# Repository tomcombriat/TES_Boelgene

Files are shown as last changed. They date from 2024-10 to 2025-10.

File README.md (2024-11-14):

# TES - Bølgene

Bølgene is a digital instrument inspired by the [Ondes Martenot](https://en.wikipedia.org/wiki/Ondes_Martenot), a contemporary instrument to the Theremin.
The original instrument features a force sensitive button for the expression/volume and continuous pitch controlled by the position of a ring.

Bølgene is a small, table-top, digital, instrument having the base features. The main differences is that it features polyphony, with several pressure sensitive buttons.

Bølgene (first version) was created in a few weeks specially for [Oslo Skaper Festival 2024](https://norwaymakers.org/osf24). 

## v1

### Hardware

Nothing special here except a well sized plank, found in the street. Apart from that…
 - CPU: RP2040
 - additionnal ADC: MCP3008
 - DAC: PT8211
 - expressions buttons: 4
 - synthesis potentiometers:

Made on single sided PCB.

### Software
 - sound system: [Mozzi](https://sensorium.github.io/Mozzi/)

#### boelgene_1

The version presented at Oslo Skaper Festival, monophonic with Delay Feedback creating weird sounds, especially in the bass register.

#### boelgene_poly 

Version supporting 4 expression buttons, currently tuned to the fifth and the two thirds. Uses the same synthesis algorithm than boelgene_v1

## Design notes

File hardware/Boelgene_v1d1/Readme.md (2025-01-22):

# Building instructions and details

This document contains details and building information for Bølgene v1.1.

## General information

This version of Bølgene is a small step from the v1 which was based on a one-sided PCB.
As the previous version, this is based on a Raspberry Pico (RP2040) MCU and a PT8211 DAC. Because of the low number of analog inputs on the RP2040, a companion ADC is also used.

## Audio modes

The PCB supports three audio modes:

 - PWM straight from the RP2040. Resolution is 12bits. All DAC components can then be omitted (PT8211, C9, C10, C11 and C12) and normally C2, C3 and R1.
 - mono output: components for the PWM can be omitted (C7 and C8) and components for the right channel (C10, C12). This outputs a 16bits signal on `out_dac1`.
 - stereo output: components for the PWM can be omitted (C7 and C8). This outputs a 16bits signal on `out_dac1` and `out_dac2`.
 
All outputs do not have volume control as of the PCB. An external log potentiometer can be adjucted.

## Analog inputs

There are a few analog signals that are measured:

### Pressure (touch):

These are measured wih the help of resisor dividers (RV1-4) and are to be connected to force sensitive resistors (range 1.5kg, ref in BOM). The pots are adjusting the sensitivity of the pressure sensors.

## Ribbon

This is to be connected to the central pin of a 10 turns, 10k linear potentiometer. The other two pins should be connected to GNDA and ADC_ref. 

## Synthesis input

There are currently 5 potentiometers to adjust the synthesis parameters. There is a free slot so a sixth could be added.

The test points labelled pot1-5 are to be connected to the central pin (10k linear), and the other two to GNDA and ADC_ref.

## Power

As of now, the system is powered by four AA batteries giving a nominal voltage of 4*1.2 = 4.8V. The only limitation there are the IC voltage tolerances: RP2040 is given fine up to 6V, PT8211 up to 7V.

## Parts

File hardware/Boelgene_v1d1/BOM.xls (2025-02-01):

Id | Référence | Boîtier | Quantité | Désignation | Fournisseur et réf | Extra info
1 | R3 | R_Axial_DIN0207_L6.3mm_D2.5mm_P7.62mm_Horizontal | 1 | 220
2 | TP18 | TestPoint_THTPad_2.0x2.0mm_Drill1.0mm | 1 | Ref- |  | Sound board, low point reference switch (switch is to shut to GND)
3 | H1,H3,H4,H2 | MountingHole_3.2mm_M3 | 4 | MountingHole
4 | TP7,TP8,TP12,TP6,TP5,TP1 | TestPoint_THTPad_2.0x2.0mm_Drill1.0mm | 6 | GND
5 | TP22,TP24,TP23,TP25,TP21,TP26 | TestPoint_THTPad_2.0x2.0mm_Drill1.0mm | 6 | GNDA |  | Analog Ground
6 | TP33 | TestPoint_THTPad_2.0x2.0mm_Drill1.0mm | 1 | pot4
7 | TP17 | TestPoint_THTPad_2.0x2.0mm_Drill1.0mm | 1 | LED
8 | TP16 | TestPoint_THTPad_2.0x2.0mm_Drill1.0mm | 1 | D5 |  | Unused
9 | C6 | CP_Radial_D5.0mm_P2.00mm | 1 | 1u
10 | J3 | JST_XH_B2B-XH-A_1x02_P2.50mm_Vertical | 1 | pressure2 |  | To be connected to a force sensitive resistor like : https://fr.aliexpress.com/item/1005006212871655.html
11 | J4 | JST_XH_B2B-XH-A_1x02_P2.50mm_Vertical | 1 | pressure1 |  | To be connected to a force sensitive resistor like : https://fr.aliexpress.com/item/1005006212871655.html
12 | J1 | JST_XH_B2B-XH-A_1x02_P2.50mm_Vertical | 1 | batt |  | Battery input (4.5-6V)
13 | TP9,TP10,TP3,TP11,TP2,TP4 | TestPoint_THTPad_2.0x2.0mm_Drill1.0mm | 6 | ADC_ref
14 | TP43 | TestPoint_THTPad_2.0x2.0mm_Drill1.0mm | 1 | out_PWM |  | Audio output for PWM mode
15 | J5 | JST_XH_B2B-XH-A_1x02_P2.50mm_Vertical | 1 | pressure4 |  | To be connected to a force sensitive resistor like : https://fr.aliexpress.com/item/1005006212871655.html
16 | U1 | RPi_Pico_SMD_TH | 1 | Pico |  | Raspberry pico 2040
17 | RV2 | Potentiometer_Runtron_RM-065_Vertical | 1 | 20k_adj2
18 | RV3 | Potentiometer_Runtron_RM-065_Vertical | 1 | 20k_adj1
19 | TP13 | TestPoint_THTPad_2.0x2.0mm_Drill1.0mm | 1 | D2 |  | Unused
20 | C9,C11 | CP_Radial_D5.0mm_P2.50mm | 2 | 1u dac1
21 | TP32 | TestPoint_THTPad_2.0x2.0mm_Drill1.0mm | 1 | pot5
22 | RV4 | Potentiometer_Runtron_RM-065_Vertical | 1 | 20k_adj4
23 | C2,C4 | CP_Radial_D8.0mm_P5.00mm | 2 | 100u
24 | C5,C3 | C_Axial_L3.8mm_D2.6mm_P7.50mm_Horizontal | 2 | 100n
25 | RV1 | Potentiometer_Runtron_RM-065_Vertical | 1 | 20k_adj3
26 | R1,R2 | R_Axial_DIN0207_L6.3mm_D2.5mm_P7.62mm_Horizontal | 2 | 10
27 | TP14 | TestPoint_THTPad_2.0x2.0mm_Drill1.0mm | 1 | Ref+ |  | Sound board, high point reference switch
28 | C10,C12 | CP_Radial_D5.0mm_P2.50mm | 2 | 1u dac2 |  | Unused in Mono
29 | TP19 | TestPoint_THTPad_2.0x2.0mm_Drill1.0mm | 1 | Oct+ |  | Oct + switch (switch should shut to GND)
30 | TP42 | TestPoint_THTPad_2.0x2.0mm_Drill1.0mm | 1 | 3.3V
31 | TP35 | TestPoint_THTPad_2.0x2.0mm_Drill1.0mm | 1 | pot2
32 | TP20 | TestPoint_THTPad_2.0x2.0mm_Drill1.0mm | 1 | Oct-
33 | TP28 | TestPoint_THTPad_2.0x2.0mm_Drill1.0mm | 1 | AI27 |  | Ribbon (linear 10 turn pot 10k) input : https://fr.aliexpress.com/item/1005003756851148.html
34 | TP27 | TestPoint_THTPad_2.0x2.0mm_Drill1.0mm | 1 | AI28 |  | Unused (free analog channel)
35 | J2 | JST_XH_B2B-XH-A_1x02_P2.50mm_Vertical | 1 | pressure3 |  | To be connected to a force sensitive resistor like : https://fr.aliexpress.com/item/1005006212871655.html
36 | TP44 | TestPoint_THTPad_2.0x2.0mm_Drill1.0mm | 1 | out_dac1 |  | Audio output for Mono and Left for stereo
37 | TP36 | TestPoint_THTPad_2.0x2.0mm_Drill1.0mm | 1 | pot1
38 | C1 | C_Axial_L3.8mm_D2.6mm_P7.50mm_Horizontal | 1 | 0.1u
39 | TP15 | TestPoint_THTPad_2.0x2.0mm_Drill1.0mm | 1 | D4 |  | Unused
40 | TP34 | TestPoint_THTPad_2.0x2.0mm_Drill1.0mm | 1 | pot3
41 | U2 | DIP-16_W7.62mm | 1 | MCP3008 |  | external ADC
42 | C7,C8 | CP_Radial_D5.0mm_P2.50mm | 2 | 1u pwm
43 | TP45 | TestPoint_THTPad_2.0x2.0mm_Drill1.0mm | 1 | out_dac2 |  | Unused in Mono
44 | U3 | SOP-8_3.9x4.9mm_P1.27mm | 1 | PT8211-pt8211 |  | DAC

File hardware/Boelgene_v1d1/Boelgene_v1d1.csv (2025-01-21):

Id | Référence | Boîtier | Quantité | Désignation | Fournisseur et réf
1 | R3 | R_Axial_DIN0207_L6.3mm_D2.5mm_P7.62mm_Horizontal | 1 | 220
2 | TP18 | TestPoint_THTPad_2.0x2.0mm_Drill1.0mm | 1 | Ref-
3 | H1,H3,H4,H2 | MountingHole_3.2mm_M3 | 4 | MountingHole
4 | TP7,TP8,TP12,TP6,TP5,TP1 | TestPoint_THTPad_2.0x2.0mm_Drill1.0mm | 6 | GND
5 | TP22,TP24,TP23,TP25,TP21,TP26 | TestPoint_THTPad_2.0x2.0mm_Drill1.0mm | 6 | GNDA
6 | TP33 | TestPoint_THTPad_2.0x2.0mm_Drill1.0mm | 1 | pot4
7 | TP17 | TestPoint_THTPad_2.0x2.0mm_Drill1.0mm | 1 | LED
8 | TP16 | TestPoint_THTPad_2.0x2.0mm_Drill1.0mm | 1 | D5
9 | C6 | CP_Radial_D5.0mm_P2.00mm | 1 | 1u
10 | J3 | JST_XH_B2B-XH-A_1x02_P2.50mm_Vertical | 1 | pressure2
11 | J4 | JST_XH_B2B-XH-A_1x02_P2.50mm_Vertical | 1 | pressure1
12 | J1 | JST_XH_B2B-XH-A_1x02_P2.50mm_Vertical | 1 | batt
13 | TP9,TP10,TP3,TP11,TP2,TP4 | TestPoint_THTPad_2.0x2.0mm_Drill1.0mm | 6 | ADC_ref
14 | TP43 | TestPoint_THTPad_2.0x2.0mm_Drill1.0mm | 1 | out_PWM
15 | J5 | JST_XH_B2B-XH-A_1x02_P2.50mm_Vertical | 1 | pressure4
16 | U1 | RPi_Pico_SMD_TH | 1 | Pico
17 | RV2 | Potentiometer_Runtron_RM-065_Vertical | 1 | 20k_adj2
18 | RV3 | Potentiometer_Runtron_RM-065_Vertical | 1 | 20k_adj1
19 | TP13 | TestPoint_THTPad_2.0x2.0mm_Drill1.0mm | 1 | D2
20 | C9,C11 | CP_Radial_D5.0mm_P2.50mm | 2 | 1u dac1
21 | TP32 | TestPoint_THTPad_2.0x2.0mm_Drill1.0mm | 1 | pot5
22 | RV4 | Potentiometer_Runtron_RM-065_Vertical | 1 | 20k_adj4
23 | C2,C4 | CP_Radial_D8.0mm_P5.00mm | 2 | 100u
24 | C5,C3 | C_Axial_L3.8mm_D2.6mm_P7.50mm_Horizontal | 2 | 100n
25 | RV1 | Potentiometer_Runtron_RM-065_Vertical | 1 | 20k_adj3
26 | R1,R2 | R_Axial_DIN0207_L6.3mm_D2.5mm_P7.62mm_Horizontal | 2 | 10
27 | TP14 | TestPoint_THTPad_2.0x2.0mm_Drill1.0mm | 1 | Ref+
28 | C10,C12 | CP_Radial_D5.0mm_P2.50mm | 2 | 1u dac2
29 | TP19 | TestPoint_THTPad_2.0x2.0mm_Drill1.0mm | 1 | Oct+
30 | TP42 | TestPoint_THTPad_2.0x2.0mm_Drill1.0mm | 1 | 3.3V
31 | TP35 | TestPoint_THTPad_2.0x2.0mm_Drill1.0mm | 1 | pot2
32 | TP20 | TestPoint_THTPad_2.0x2.0mm_Drill1.0mm | 1 | Oct-
33 | TP28 | TestPoint_THTPad_2.0x2.0mm_Drill1.0mm | 1 | AI27
34 | TP27 | TestPoint_THTPad_2.0x2.0mm_Drill1.0mm | 1 | AI28
35 | J2 | JST_XH_B2B-XH-A_1x02_P2.50mm_Vertical | 1 | pressure3
36 | TP44 | TestPoint_THTPad_2.0x2.0mm_Drill1.0mm | 1 | out_dac1
37 | TP36 | TestPoint_THTPad_2.0x2.0mm_Drill1.0mm | 1 | pot1
38 | C1 | C_Axial_L3.8mm_D2.6mm_P7.50mm_Horizontal | 1 | 0.1u
39 | TP15 | TestPoint_THTPad_2.0x2.0mm_Drill1.0mm | 1 | D4
40 | TP34 | TestPoint_THTPad_2.0x2.0mm_Drill1.0mm | 1 | pot3
41 | U2 | DIP-16_W7.62mm | 1 | MCP3008
42 | C7,C8 | CP_Radial_D5.0mm_P2.50mm | 2 | 1u pwm
43 | TP45 | TestPoint_THTPad_2.0x2.0mm_Drill1.0mm | 1 | out_dac2
44 | U3 | SOP-8_3.9x4.9mm_P1.27mm | 1 | PT8211-pt8211

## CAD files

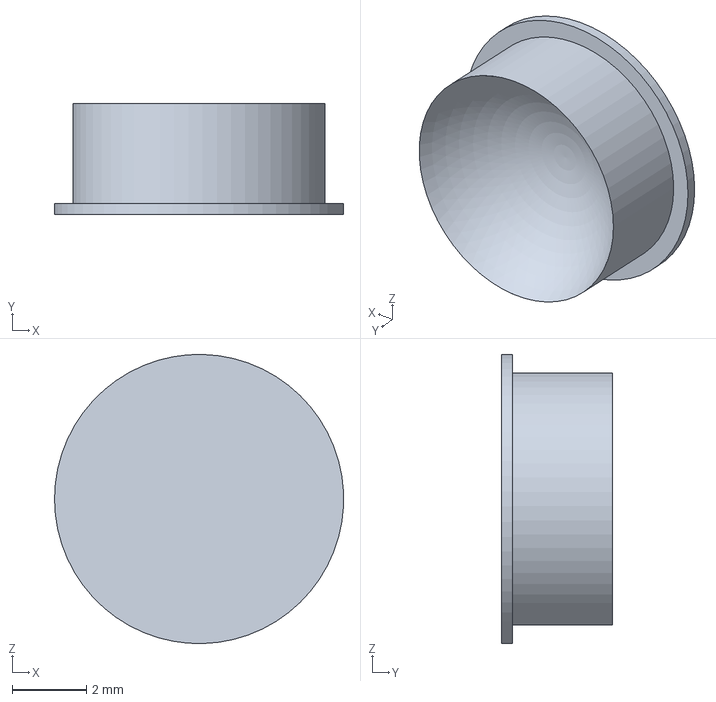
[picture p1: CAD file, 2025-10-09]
hardware/3D_proto2/FingerBoard/full_fret.FCStd
7.79 x 3.00 x 7.80 mm

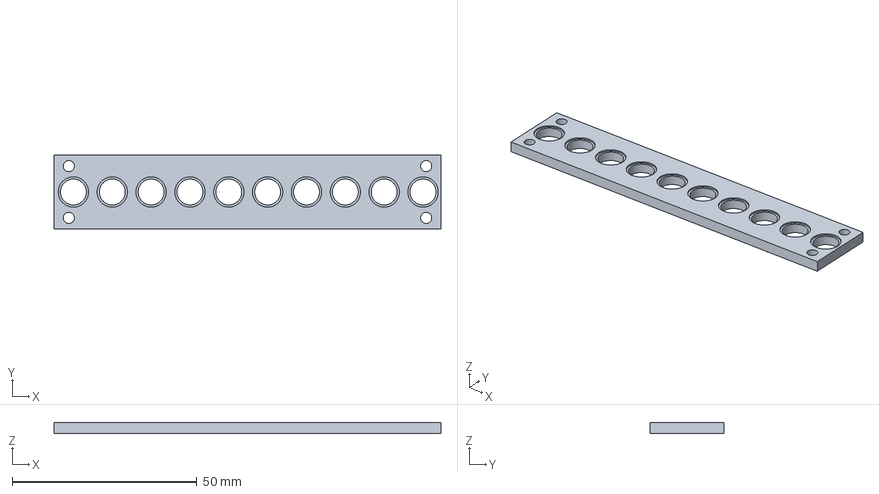
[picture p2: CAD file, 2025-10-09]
hardware/3D_proto2/FingerBoard/half_base_20holes.FCStd
104.6 x 20.0 x 3.00 mm

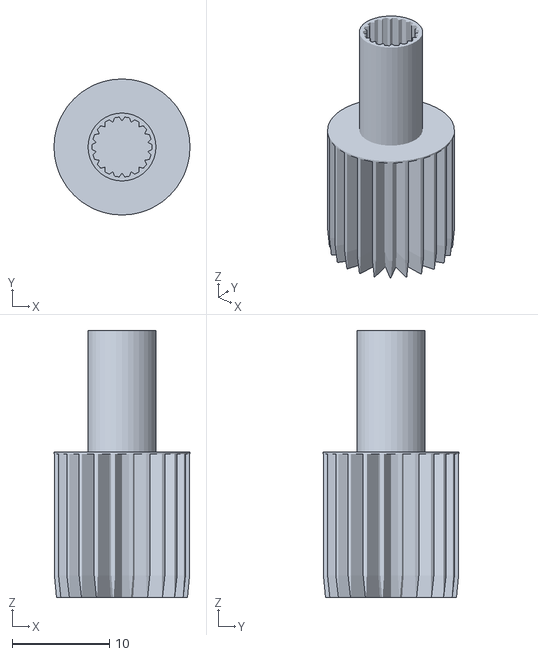
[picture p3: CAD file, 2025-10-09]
hardware/3D_proto2/pot_top4_part1.STL
14.0 x 14.0 x 27.5

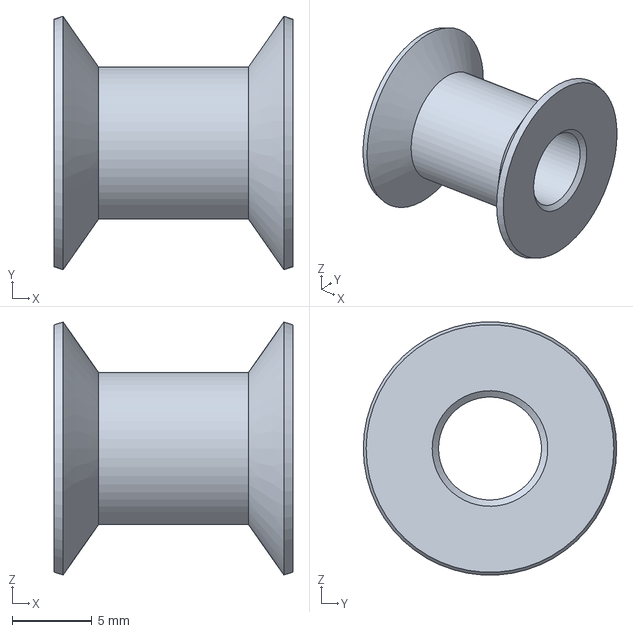
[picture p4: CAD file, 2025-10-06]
hardware/3D_proto2/Ribbon/potentiometer_pulley.FCStd
15.0 x 15.9 x 15.9 mm

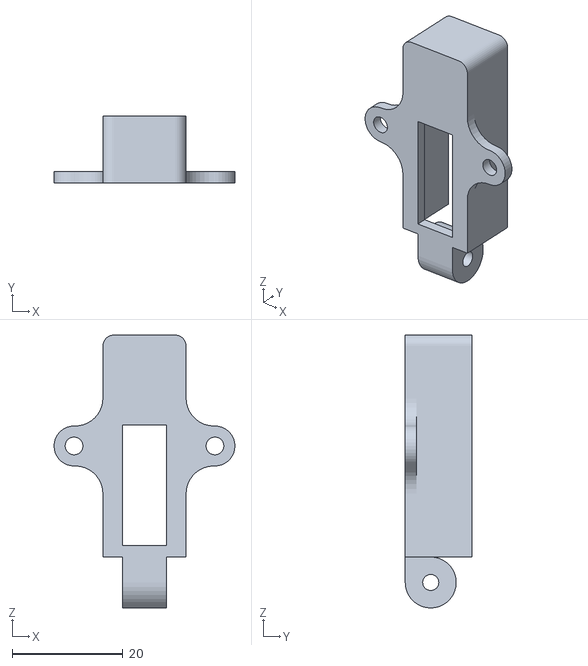
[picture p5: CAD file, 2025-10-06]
hardware/3D_proto2/Volume_Button/Bottom_common_1.STL
32.6 x 12.0 x 49.2

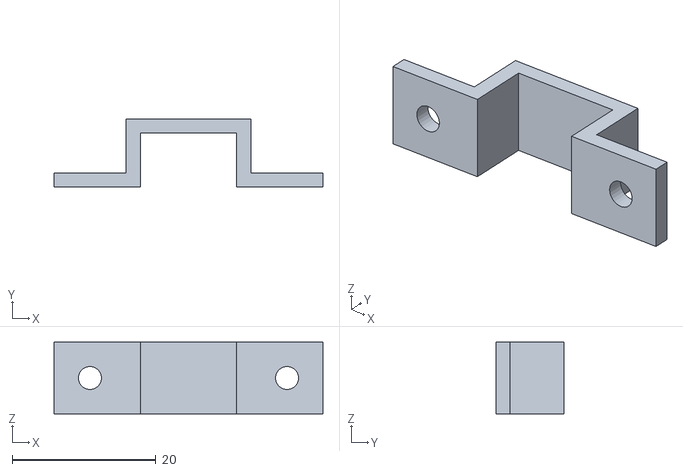
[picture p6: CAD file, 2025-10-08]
hardware/3D_proto2/OnOff_holder-Corps.stl
37.4 x 9.50 x 10.0

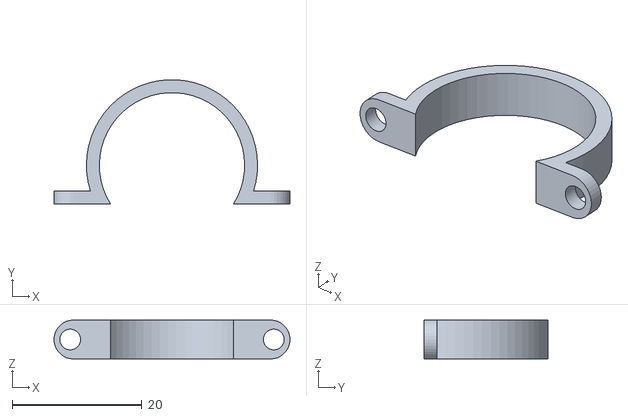
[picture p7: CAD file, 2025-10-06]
hardware/3D_proto2/Ribbon/top_potentiometer.STL
36.4 x 19.2 x 6.00

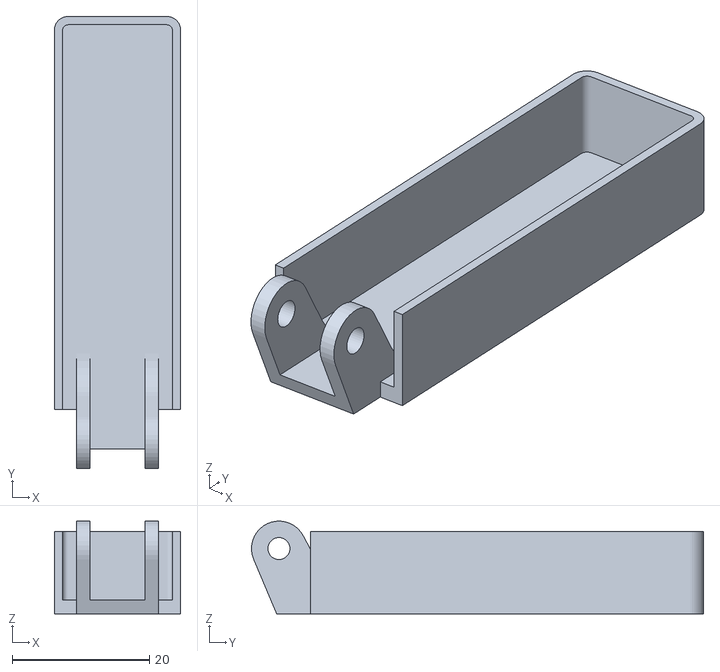
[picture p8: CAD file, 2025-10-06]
hardware/3D_proto2/Volume_Button/Top_oversize_1.STL
18.4 x 65.8 x 13.5

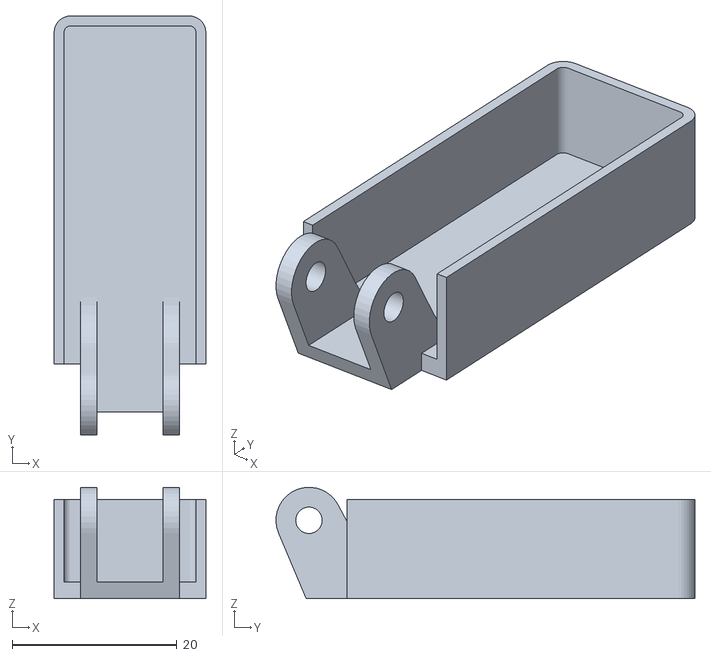
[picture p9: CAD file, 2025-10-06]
hardware/3D_proto2/Volume_Button/Top_common_1.STL
18.4 x 50.8 x 13.5

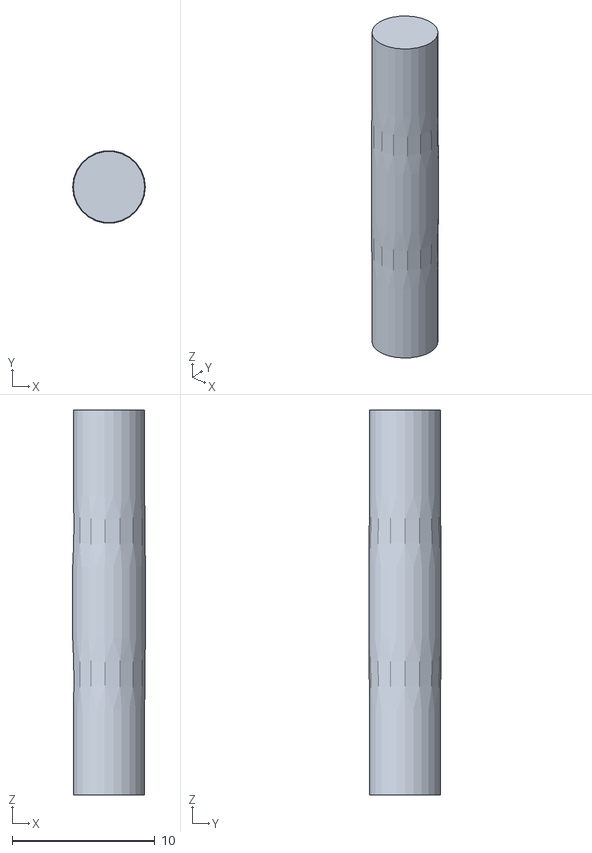
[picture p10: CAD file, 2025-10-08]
hardware/3D_proto2/axis_small_idler_bump-Corps.stl
5.10 x 5.06 x 27.0

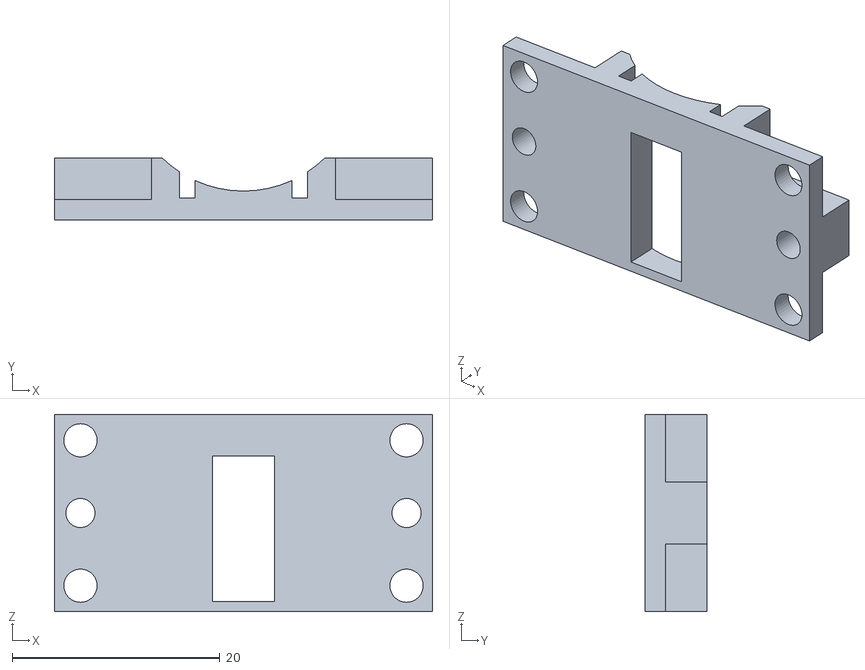
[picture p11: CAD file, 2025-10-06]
hardware/3D_proto2/Ribbon/bottom_potentiometer.STL
36.4 x 6.00 x 19.0

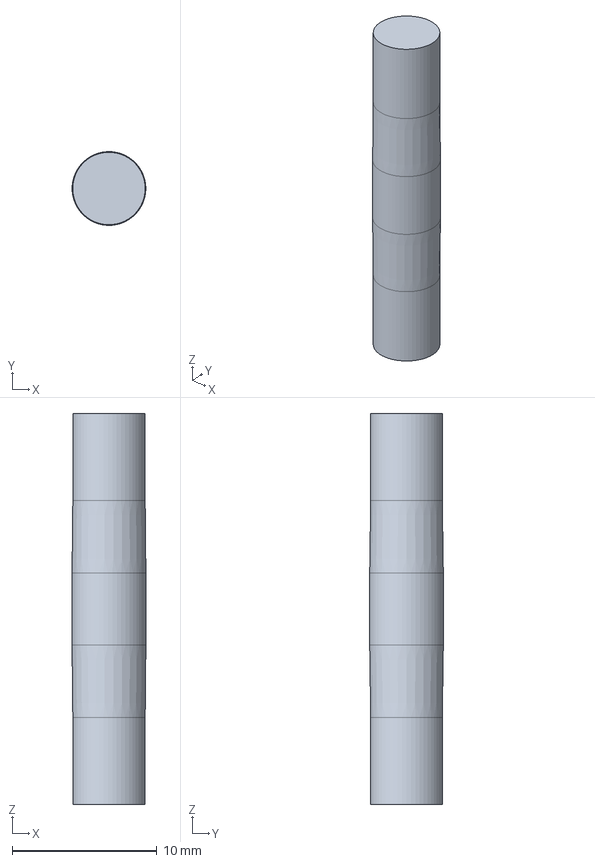
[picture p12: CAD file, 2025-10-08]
hardware/3D_proto2/axis_small_idler_bump.FCStd
5.10 x 5.10 x 27.0 mm

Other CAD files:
hardware/3D_proto2/FingerBoard/full_fret-Corps.stl
hardware/3D_proto2/FingerBoard/assembly.FCStd
hardware/3D_proto2/OnOff_holder.FCStd
hardware/3D_proto2/Ribbon/potentiometer_pulley-Corps.stl
hardware/3D_proto2/FingerBoard/half_base_13holes.FCStd
hardware/3D_proto2/FingerBoard/half_base-Corps.stl
hardware/3D_proto2/FingerBoard/half_base.FCStd
hardware/3D_proto2/FingerBoard/half_base_13holes-Corps.stl
hardware/3D_proto2/FingerBoard/half_base_20holes-Corps.stl
hardware/3D_proto2/axis_small_idler-Corps.stl
hardware/3D_proto2/axis_small_idler.FCStd
hardware/3D_proto2/battery_holder.STL
hardware/3D_proto2/cable_holder.STL
hardware/3D_proto2/cover_small_idler_holder-cover.stl
hardware/3D_proto2/cover_small_idler_holder.FCStd
hardware/3D_proto2/jack_support.STL
hardware/3D_proto2/small_idler-Corps.stl
hardware/3D_proto2/small_idler.FCStd
hardware/3D_proto2/small_idler_holder-holder.stl
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

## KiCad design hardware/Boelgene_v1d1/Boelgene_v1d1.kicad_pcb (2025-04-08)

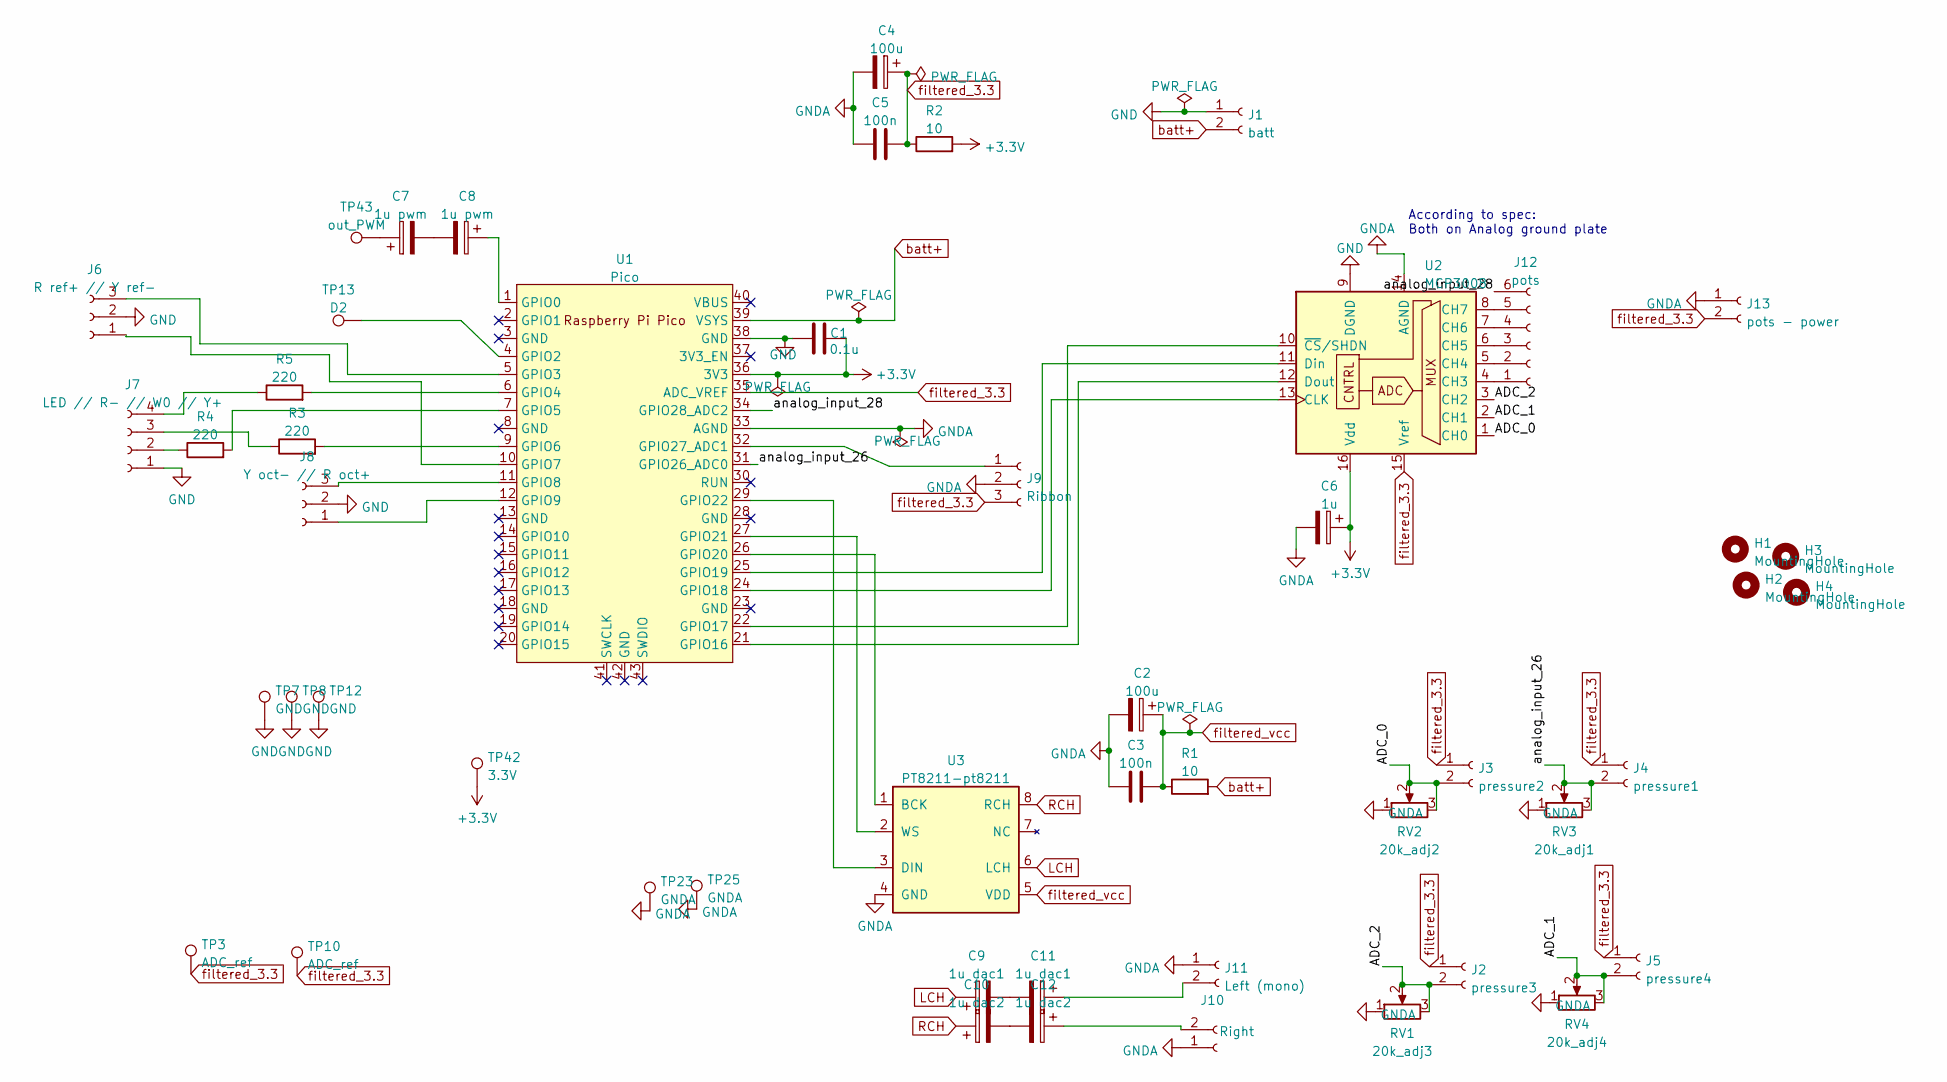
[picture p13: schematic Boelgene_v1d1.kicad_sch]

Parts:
C1: 0.1u; C_Axial_L3.8mm_D2.6mm_P7.50mm_Horizontal
C2, C4: 100u; CP_Radial_D8.0mm_P5.00mm
C3, C5: 100n; C_Axial_L3.8mm_D2.6mm_P7.50mm_Horizontal
C6: 1u; CP_Radial_D5.0mm_P2.00mm
C7, C8: 1u pwm; CP_Radial_D5.0mm_P2.50mm
C9, C11: 1u dac1; CP_Radial_D5.0mm_P2.50mm
C10, C12: 1u dac2; CP_Radial_D5.0mm_P2.50mm
H1, H2, H3, H4: MountingHole; MountingHole_3.2mm_M3
J1: batt; JST_XH_B2B-XH-A_1x02_P2.50mm_Vertical
J2: pressure3; JST_XH_B2B-XH-A_1x02_P2.50mm_Vertical
J3: pressure2; JST_XH_B2B-XH-A_1x02_P2.50mm_Vertical
J4: pressure1; JST_XH_B2B-XH-A_1x02_P2.50mm_Vertical
J5: pressure4; JST_XH_B2B-XH-A_1x02_P2.50mm_Vertical
J6: R ref+ // Y ref-; JST_PH_B3B-PH-K_1x03_P2.00mm_Vertical
J7: LED // R- // W0 // Y+; JST_PH_B4B-PH-K_1x04_P2.00mm_Vertical
J8: Y oct- // R oct+; JST_PH_B3B-PH-K_1x03_P2.00mm_Vertical
J9: Ribbon; JST_PH_B3B-PH-K_1x03_P2.00mm_Vertical
J10: Right; JST_XH_B2B-XH-A_1x02_P2.50mm_Vertical
J11: Left (mono); JST_XH_B2B-XH-A_1x02_P2.50mm_Vertical
J12: pots; JST_PH_B6B-PH-K_1x06_P2.00mm_Vertical
J13: pots - power; JST_XH_B2B-XH-A_1x02_P2.50mm_Vertical
R1, R2: 10; R_Axial_DIN0207_L6.3mm_D2.5mm_P7.62mm_Horizontal
R3, R4, R5: 220; R_Axial_DIN0207_L6.3mm_D2.5mm_P7.62mm_Horizontal
RV1: 20k_adj3; Potentiometer_Runtron_RM-065_Vertical
RV2: 20k_adj2; Potentiometer_Runtron_RM-065_Vertical
RV3: 20k_adj1; Potentiometer_Runtron_RM-065_Vertical
RV4: 20k_adj4; Potentiometer_Runtron_RM-065_Vertical
TP3, TP10: ADC_ref; TestPoint_THTPad_2.0x2.0mm_Drill1.0mm
TP7, TP8, TP12: GND; TestPoint_THTPad_2.0x2.0mm_Drill1.0mm
TP13: D2; TestPoint_THTPad_2.0x2.0mm_Drill1.0mm
TP23, TP25: GNDA; TestPoint_THTPad_2.0x2.0mm_Drill1.0mm
TP42: 3.3V; TestPoint_THTPad_2.0x2.0mm_Drill1.0mm
TP43: out_PWM; TestPoint_THTPad_2.0x2.0mm_Drill1.0mm
U1: Pico; RPi_Pico_TH
U2: MCP3008; DIP-16_W7.62mm
U3: PT8211-pt8211; SOP-8_3.9x4.9mm_P1.27mm

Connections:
+3.3V: C1.2, C6.1, R2.2, TP42.1, U1.36 (3V3), U2.16 (Vdd)
/ADC_0: J3.2, RV2.2, RV2.3, U2.1 (CH0)
/ADC_1: J5.2, RV4.2, RV4.3, U2.2 (CH1)
/ADC_2: J2.2, RV1.2, RV1.3, U2.3 (CH2)
/analog_input_26: J4.2, RV3.2, RV3.3, U1.31 (GPIO26_ADC0)
/analog_input_28: J12.6, U1.34 (GPIO28_ADC2)
GND: C1.1, J1.1, J6.2, J7.1, J8.2, TP7.1, TP8.1, TP12.1, U1.38 (GND), U2.9 (DGND)
GNDA: C2.2, C3.2, C4.2, C5.2, C6.2, J9.2, J10.1, J11.1, J13.1, RV1.1, RV2.1, RV3.1, RV4.1, TP23.1, TP25.1, U1.33 (AGND), U2.14 (AGND), U3.4 (GND)
LCH: C9.1, U3.6 (LCH)
unnamed: C7.1, TP43.1
unnamed: C7.2, C8.2
unnamed: C8.1, U1.1 (GPIO0)
unnamed: C10.2, C12.2
unnamed: C11.1, J11.2
unnamed: C9.2, C11.2
unnamed: C12.1, J10.2
unnamed: J6.1, U1.10 (GPIO7)
unnamed: J6.3, U1.5 (GPIO3)
unnamed: J7.2, R4.1
unnamed: J7.3, R3.1
unnamed: J7.4, R5.1
unnamed: J8.1, U1.12 (GPIO9)
unnamed: J8.3, U1.11 (GPIO8)
unnamed: J9.1, U1.32 (GPIO27_ADC1)
unnamed: J12.1, U2.4 (CH3)
unnamed: J12.2, U2.5 (CH4)
unnamed: J12.3, U2.6 (CH5)
unnamed: J12.4, U2.7 (CH6)
unnamed: J12.5, U2.8 (CH7)
unnamed: R3.2, U1.9 (GPIO6)
unnamed: R4.2, U1.7 (GPIO5)
unnamed: R5.2, U1.6 (GPIO4)
unnamed: TP13.1, U1.4 (GPIO2)
unnamed: U1.21 (GPIO16), U2.12 (Dout)
unnamed: U1.22 (GPIO17), U2.10 (~CS/SHDN)
unnamed: U1.24 (GPIO18), U2.13 (CLK)
unnamed: U1.25 (GPIO19), U2.11 (Din)
unnamed: U1.26 (GPIO20), U3.1 (BCK)
unnamed: U1.27 (GPIO21), U3.2 (WS)
unnamed: U1.29 (GPIO22), U3.3 (DIN)
RCH: C10.1, U3.8 (RCH)
batt+: J1.2, R1.2, U1.39 (VSYS)
filtered_3.3: C4.1, C5.1, J2.1, J3.1, J4.1, J5.1, J9.3, J13.2, R2.1, TP3.1, TP10.1, U1.35 (ADC_VREF), U2.15 (Vref)
filtered_vcc: C2.1, C3.1, R1.1, U3.5 (VDD)

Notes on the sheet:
According to spec: Both on Analog ground plate

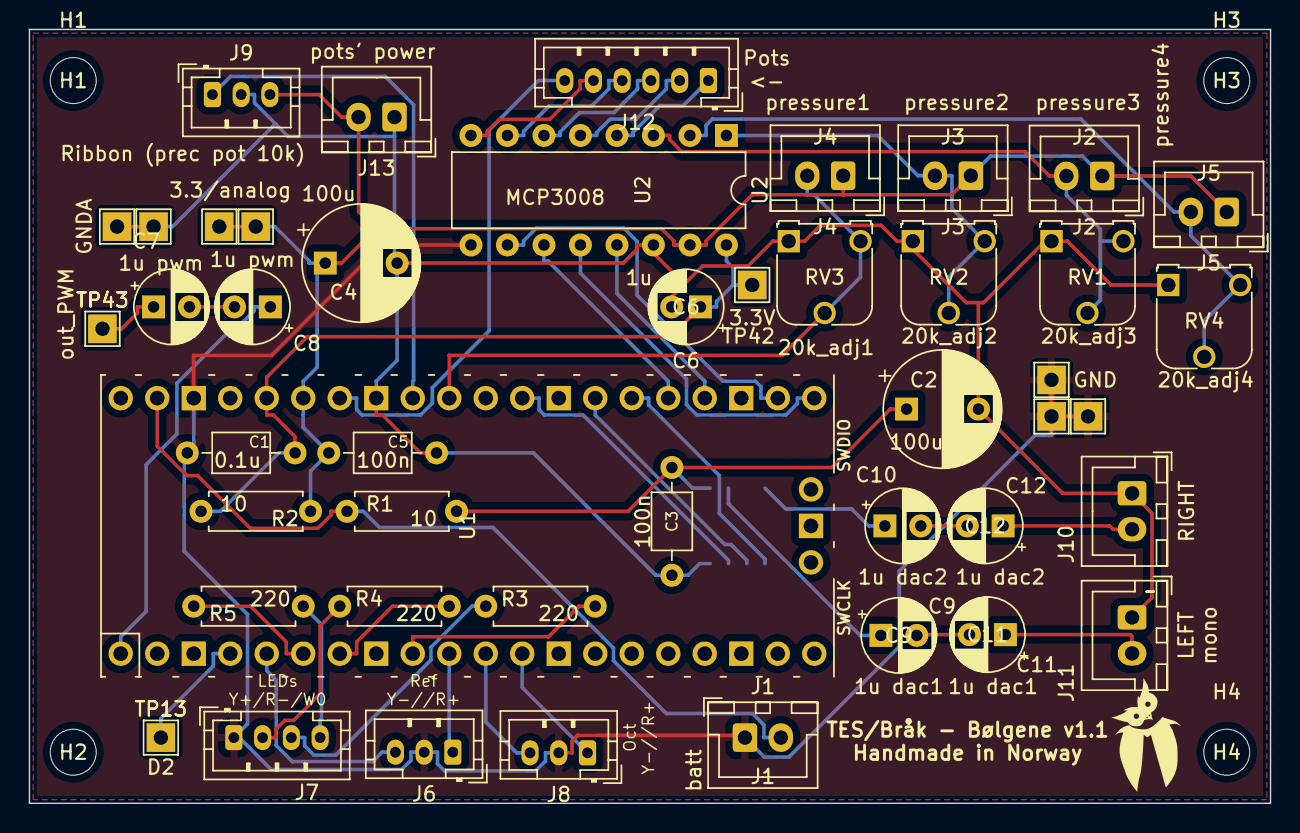
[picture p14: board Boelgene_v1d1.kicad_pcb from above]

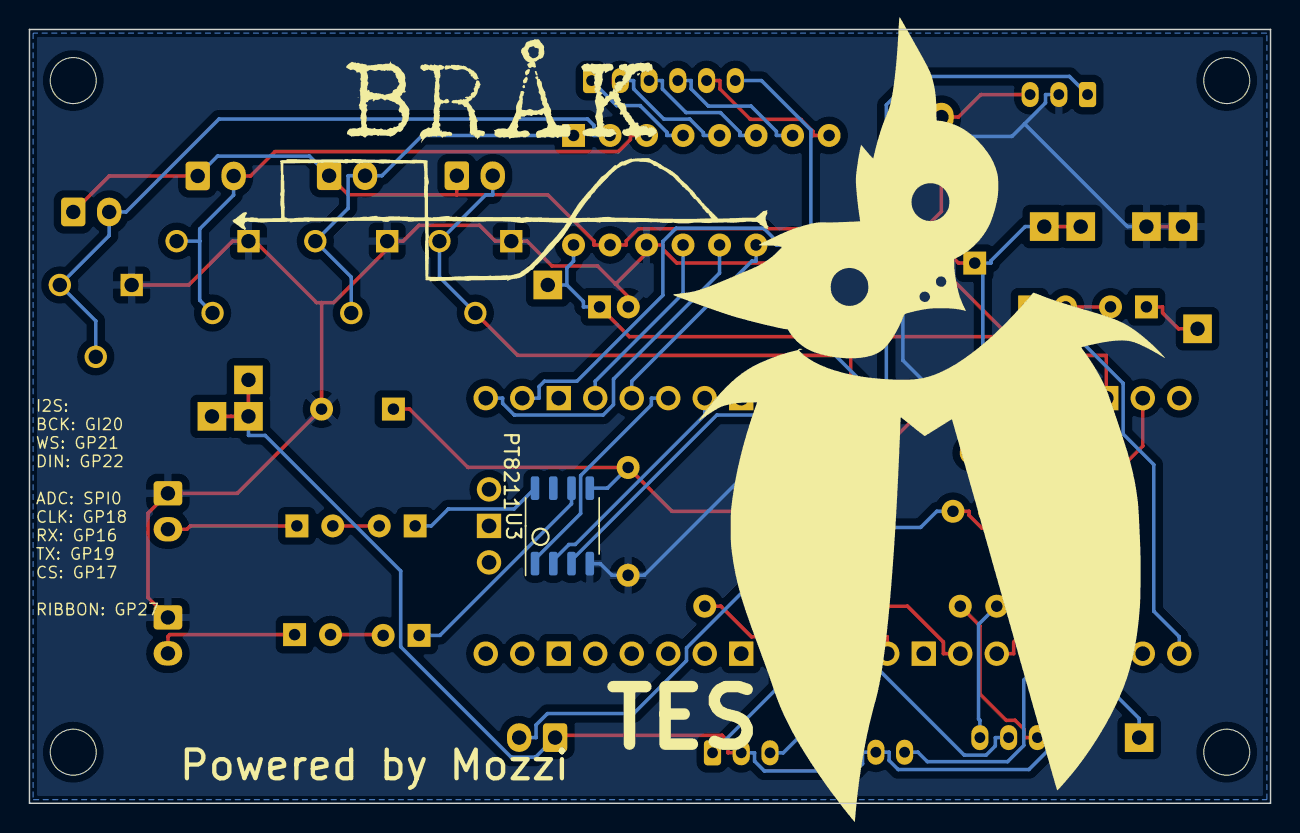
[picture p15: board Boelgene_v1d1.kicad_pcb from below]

Board: 2 copper layers, 86.4 x 53.8 mm, 52 parts (2 on the bottom side), 44 nets.

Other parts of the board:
G150: LOGO; owl_F_50x70

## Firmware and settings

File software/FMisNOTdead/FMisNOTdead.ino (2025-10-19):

/*
Copyright 2024 Thomas Combriat

This is licensed under the GPL Licence

This is the main code for the poly-Boelgene, a polyphonic version
of a small Ondes Nartenot replica.

It features four pressure buttons instead of one, allowing
different notes to be played simulteanously.


TODO: 
 - maybe make BiPot more efficient by changing const values with templates
*/

#include "MozziConfigValues.h"  // for named option values
#include "config.h"

#define MOZZI_AUDIO_CHANNELS 1
#define MOZZI_CONTROL_RATE 1024  // Hz, powers of 2 are most reliable
//#define MOZZI_CONTROL_RATE 256  // Hz, powers of 2 are most reliable

#include <Button.h>  // from TES_eSax-lib
#include <Mozzi.h>
#include <mozzi_midi.h>
#include <Oscil.h>
#include <tables/saw2048_int8.h>
//#include <tables/triangle2048_int8.h>
#include <tables/cos2048_int8.h>
#include <ResonantFilter.h>
#include <FixMathMapper.h>
#include "BiPot.h"
#include <MetaOscil.h>
#include "Oscils.h"

#include <SPI.h>
#include <MCP3XXX.h>


#if (defined LUT_FM_RATIO_FULL || defined LUT_FM_RATIO_HALF)
#include "modRatioLUT.hpp"
#endif


FixMathMapperFull<UFix<12, 0>, UFix<7, 9>> mapper;
FixMathMapperFull<UFix<12, 0>, UFix<8, 0>, true> pressure0Mapper;
FixMathMapperFull<UFix<10, 0>, UFix<8, 0>, true> pressure1Mapper;
FixMathMapperFull<UFix<10, 0>, UFix<8, 0>, true> pressure2Mapper;
FixMathMapperFull<UFix<10, 0>, UFix<8, 0>, true> pressure3Mapper;

// ADC
MCP3XXX_<10, 8, 300000> adc;


// Pin mapping
const uint8_t pot0 = 3, pot1 = 4, pot2 = 5, pot3 = 6, pot4 = 7, pot5 = 28;
const uint8_t pitch_pin = 27, octm_pin = 9, octp_pin = 8, refm_pin = 7, refp_pin = 3;
const uint8_t pressure_pin0 = 26, pressure_pin1 = 0, pressure_pin2 = 1, pressure_pin3 = 2;

// Octaves plus and minus buttons
Button octm(octm_pin, false);
Button octp(octp_pin, false);

// Global synthesis variables
int octave = 0;
UFix<7, 9> midi_base_note;
UFix<12, 0> pitch_pot_min = 433, pitch_pot_max = 3811;
bool delay_on = false;
uint16_t resonance = 0;  //, cutoff = 0;
UFix<2, 8> mod1Ratio, prevMod1Ratio;
UFix<2, 8> mod2Ratio, prevMod2Ratio;




unsigned long last_update_time = 0;

/// LED false Osc
uint8_t led_intensity = 0;
Oscil<COS2048_NUM_CELLS, MOZZI_CONTROL_RATE> kCosLed1(COS2048_DATA);
Oscil<COS2048_NUM_CELLS, MOZZI_CONTROL_RATE> kCosLed2(COS2048_DATA);


// Maybe boost back to 1 once pressure properly calibrated?
BiPotMultBoost cutoffPot(10, 8, 1);
BiPotMultBoost mod1Pot(10, 8, 1);
BiPotMultBoost mod1RatioPot(10);

BiPotMultBoost mod2Pot(12, 8, 1);  // 12 because we use an internal DAC here, and not the external 10 bits dac
BiPotMultBoost mod2RatioPot(10);


#define N_VOICES 4
#define OSC_NUM_CELLS 2048
class voice {
public:  // no offense, most things in public, I know what I am doing
  Oscil<OSC_NUM_CELLS, MOZZI_AUDIO_RATE> aCos;
  Oscil<OSC_NUM_CELLS, MOZZI_AUDIO_RATE> aMod1;
  Oscil<OSC_NUM_CELLS, MOZZI_AUDIO_RATE> aMod2;
  Oscil<OSC_NUM_CELLS, MOZZI_AUDIO_RATE> aSub;
  //AudioDelayFeedback<2048> aDel;
  SFix<4, 0> transpose;

  uint8_t volume;
  LowPassFilter16 lpf;
  uint16_t cutoff;

  void setFreq(UFix<16, 16> _freq) {
    anti_alias(_freq, modulation_amount1, modulation_amount2);
    aCos.setFreq(freq);
    aSub.setFreq(freq.sR<1>());
    aMod1.setFreq(freq * mod1Ratio);
    aMod2.setFreq(freq * mod2Ratio);
  };

  void setMod1(uint16_t mod1) {
    anti_alias(freq, mod1, modulation_amount2);
  };
  void setMod2(uint16_t mod2) {
    anti_alias(freq, modulation_amount1, mod2);
  };

  uint16_t getMod1() {
    return modulation_amount1;
  };
  uint16_t getMod2() {
    return modulation_amount2;
  };

  UFix<16, 16> getFreq() {
    return freq;
  };



private:
  uint16_t modulation_amount1, modulation_amount2;
  UFix<16, 16> freq;
  void anti_alias(UFix<16, 16> _freq, uint16_t mod1, uint16_t mod2) {
    UFix<0, 8> B = 0.0075 * 2;                                                                           // 3 removes more aliases, but changes a lot the sound
    auto den = (_freq * mod1Ratio * (UFixAuto<1>() + ((B * mod2Ratio * (UFix<16, 0>(mod2).sR<7>())))));  // denominator
    uint32_t m1 = (uint32_t(16000 * 74) / den.asInt()) << 4;
    if (m1 < mod1) modulation_amount1 = m1;  // if mod1 too big, we tame down to m1, limit to not have aliases
    else modulation_amount1 = mod1;
    freq = _freq;
    modulation_amount2 = mod2;
  };
};


voice voices[N_VOICES];

void setup() {

  Serial.begin(115200);
  // Voices initialization
  for (int i = 0; i < N_VOICES; i++) {
    voices[i].aCos.setTable(COS2048_DATA);
    voices[i].aMod1.setTable(COS2048_DATA);
    voices[i].aMod2.setTable(COS2048_DATA);
    voices[i].aSub.setTable(COS2048_DATA);
  }
  voices[0].transpose = 0;
  voices[1].transpose = 4;
  voices[2].transpose = 3;
  voices[3].transpose = 7;

  pinMode(pressure_pin0, INPUT);
  pinMode(pitch_pin, INPUT);
  pinMode(pot5, INPUT);

  pinMode(led_pin, OUTPUT);

  pinMode(23, OUTPUT);  // thi is to switch to PWM for power to avoid ripple noise
  digitalWrite(23, HIGH);

  pinMode(LED_BUILTIN, OUTPUT);
  digitalWrite(LED_BUILTIN, HIGH);

  // Mapper from rotary pot value to midi note (from FixMath)
  mapper.setBounds(pitch_pot_min, pitch_pot_max, 48, 48 + 24);

  pressure0Mapper.setBounds(PRESSURE0_MIN, PRESSURE0_MAX, 0, 255);
  pressure1Mapper.setBounds(PRESSURE1_MIN, PRESSURE1_MAX, 0, 255);
  pressure2Mapper.setBounds(PRESSURE2_MIN, PRESSURE2_MAX, 0, 255);
  pressure3Mapper.setBounds(PRESSURE3_MIN, PRESSURE3_MAX, 0, 255);


  startMozzi(MOZZI_CONTROL_RATE);

  pinMode(refm_pin, INPUT_PULLUP);  // has to be put after the start
  pinMode(refp_pin, INPUT_PULLUP);  // otherwise the pin3 is erratic, why? Might be worth an issue.
  pinMode(octm_pin, INPUT_PULLUP);
  pinMode(octp_pin, INPUT_PULLUP);

  analogWriteRange(255);
}

void setup1() {
  //Serial.begin(115200);
  SPI.setRX(16);
  SPI.setTX(19);
  SPI.setSCK(18);
  adc.begin(17);
}

void loop() {
  audioHook();
}

void loop1() {

  // Octave button checking
  octm.update();
  octp.update();

  if (octm.has_been_released()) {
    octave--;
    if (octave < -4) octave = -4;
  }

  if (octp.has_been_released()) {
    octave++;
    if (octave > 3) octave = 3;
  }

  // Parameters checking
  if (last_update_time + 2 < millis()) {
    last_update_time = millis();

    // LPF parameters checking
    resonance = adc.analogRead(pot1) << 6;

    cutoffPot.setValue(adc.analogRead(pot0));
    for (uint8_t i = 0; i < N_VOICES; i++) voices[i].cutoff = cutoffPot.getValue(voices[i].volume);


    //// MODULATION AMOUNTS
    mod1Pot.setValue(adc.analogRead(pot3));
    for (uint8_t i = 0; i < N_VOICES; i++) voices[i].setMod1(mod1Pot.getValue(voices[i].volume));

    // checked in updateControl
    for (uint8_t i = 0; i < N_VOICES; i++) voices[i].setMod2(mod2Pot.getValue(voices[i].volume));


      //// MODULATION RATIOS

#ifdef FM_RATIO_MOD_FREE
    int16_t reading = adc.analogRead(pot2);
#if defined LUT_FM_RATIO_FULL
    mod1Ratio = mod1Ratio.fromRaw(uint16_t(reading - (RATIO_LUT[reading % 256] >> LUT_FM_RATIO_TAME)));  // hope the compilo will optimize that, that's fairly easy. LUT can be shifted down to tame the effect
#elif defined LUT_FM_RATIO_HALF
    mod1Ratio = mod1Ratio.fromRaw(uint16_t(reading - (RATIO_LUT[(reading << 1) % 256] >> (1 + LUT_FM_RATIO_TAME))));
#else
    mod1Ratio = mod1Ratio.fromRaw(uint16_t(reading));
#endif

#else
    mod1RatioPot.setValue(adc.analogRead(pot2));
    if (mod1RatioPot.getMult()) mod1Ratio = mod1Ratio.fromRaw(mod1RatioPot.getValueRaw());
    else {  // constrained ratio
      mod1Ratio = UFix<2, 1>(mod1Ratio.fromRaw(mod1RatioPot.getValueRaw()));
      if (prevMod1Ratio != mod1Ratio) {
        prevMod1Ratio = mod1Ratio;
        for (uint8_t i = 0; i < N_VOICES; i++) {  // re-align the phase (pointless in free mod)
          voices[i].aCos.setPhaseFractional(0);
          voices[i].aMod1.setPhaseFractional(0);
          voices[i].aMod2.setPhaseFractional(0);
        }
      }
    }
#endif




#ifdef FM_RATIO_MOD_FREE
    reading = adc.analogRead(pot4);
#if defined LUT_FM_RATIO_FULL
    mod2Ratio = mod2Ratio.fromRaw(uint16_t(reading - (RATIO_LUT[reading % 256] >> LUT_FM_RATIO_TAME)));  // hope the compilo will optimize the division, that's fairly easy
#elif defined LUT_FM_RATIO_HALF
    mod2Ratio = mod2Ratio.fromRaw(uint16_t(reading - (RATIO_LUT[(reading << 1) % 256] >> (1 + LUT_FM_RATIO_TAME))));
#else
    mod2Ratio = mod2Ratio.fromRaw(uint16_t(reading));
#endif

#else
    mod2RatioPot.setValue(adc.analogRead(pot4));
    if (mod2RatioPot.getMult()) mod2Ratio = mod2Ratio.fromRaw(mod2RatioPot.getValueRaw());

    else {  // constrained ratio
      mod2Ratio = UFix<2, 1>(mod2Ratio.fromRaw(mod2RatioPot.getValueRaw()));
      if (prevMod2Ratio != mod2Ratio) {
        prevMod2Ratio = mod2Ratio;
        for (uint8_t i = 0; i < N_VOICES; i++) {  // re-align the phase (pointless in free mod)
          voices[i].aCos.setPhaseFractional(0);
          voices[i].aMod1.setPhaseFractional(0);
          voices[i].aMod2.setPhaseFractional(0);
        }
      }
    }
#endif
  }

  // Volume checking for additionnal buttons (here because async is not available)
  voices[1].volume = pressure1Mapper.map(adc.analogRead(pressure_pin1)).asRaw();
  voices[2].volume = pressure2Mapper.map(adc.analogRead(pressure_pin2)).asRaw();
  voices[3].volume = pressure3Mapper.map(adc.analogRead(pressure_pin3)).asRaw();
}


void updateControl() {


  /* Ref min and max */
  if (!digitalRead(refm_pin)) {
    pitch_pot_min = mozziAnalogRead<12>(pitch_pin);
    mapper.setBounds(pitch_pot_min, pitch_pot_max, REFM_NOTE, REFP_NOTE);
  }
  if (!digitalRead(refp_pin)) {
    pitch_pot_max = mozziAnalogRead<12>(pitch_pin);
    mapper.setBounds(pitch_pot_min, pitch_pot_max, REFM_NOTE, REFP_NOTE);
  }

  mod2Pot.setValue(mozziAnalogRead<12>(pot5));

  midi_base_note = mapper.map(mozziAnalogRead<12>(pitch_pin));
  midi_base_note = midi_base_note + UFixAuto<12>() * SFix<3, 0>(octave);


  for (uint8_t i = 0; i < N_VOICES; i++) {
    auto freq = mtof(midi_base_note + voices[i].transpose);
    voices[i].setFreq(freq);
  }


  voices[0].volume = pressure0Mapper.map(mozziAnalogRead<12>(pressure_pin0)).asRaw();


  for (uint8_t i = 0; i < N_VOICES; i++) voices[i].lpf.setCutoffFreqAndResonance(voices[i].cutoff, resonance);


  int32_t freqLed1 = abs((mod1Ratio.sL<1>() - UFix<3, 0>(mod1Ratio.sL<1>() + UFix<0, 1>(0.5))).sL<7>().asInt());
  int32_t freqLed2 = abs((mod2Ratio.sL<1>() - UFix<3, 0>(mod2Ratio.sL<1>() + UFix<0, 1>(0.5))).sL<7>().asInt());
  kCosLed1.setFreq(UFix<14, 2>().fromRaw(freqLed1 << 2));
  kCosLed2.setFreq(UFix<14, 2>().fromRaw(freqLed2 << 2));
  analogWrite(led_pin, (((int16_t(kCosLed1.next()) + 127)) + ((int16_t(kCosLed2.next())) >> 1) + 63) >> 1);  // ideally two leds… (use the octave indicators in future?)
}

AudioOutput updateAudio() {
  int32_t sample = 0;
  if (mod1Ratio != UFix<2, 8>(0) && mod2Ratio != UFix<2, 8>(0)) {
    for (uint8_t i = 0; i < N_VOICES; i++) {
      int32_t sub_sample = voices[i].aSub.next() + voices[i].aCos.phMod((voices[i].getMod1() * voices[i].aMod1.phMod((voices[i].getMod2() * voices[i].aMod2.next()) >> 7)) >> 4);
      sub_sample = voices[i].lpf.next(sub_sample * voices[i].volume);
      sample += sub_sample;
    }
  } else if (mod2Ratio == UFix<2, 8>(0)) {
    for (uint8_t i = 0; i < N_VOICES; i++) {
      int32_t sub_sample = voices[i].aSub.next() + voices[i].aCos.phMod((voices[i].getMod1() * voices[i].aMod1.next()) >> 4);
      sub_sample = voices[i].lpf.next(sub_sample * voices[i].volume);
      sample += sub_sample;
    }
  } else {
    for (uint8_t i = 0; i < N_VOICES; i++) {
      int32_t sub_sample = voices[i].aSub.next() + voices[i].aCos.next();
      sub_sample = voices[i].lpf.next(sub_sample * voices[i].volume);
      sample += sub_sample;
    }
  }
  return MonoOutput::fromNBit(18, sample).clip();
}

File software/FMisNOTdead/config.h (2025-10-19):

#ifndef _CONFIG_
#define _CONFIG_




// Config values, do not change
#define PROTO_V1 1
#define PROTO_V2 2
///////////////



#define HARDWARE_VERSION PROTO_V2

#if (HARDWARE_VERSION == PROTO_V1)  // big wood one
#define PRESSURE0_MIN 22
#define PRESSURE0_MAX 2380

#define PRESSURE1_MIN 0
#define PRESSURE1_MAX 640

#define PRESSURE2_MIN 0
#define PRESSURE2_MAX 635

#define PRESSURE3_MIN 0
#define PRESSURE3_MAX 750

#define MOZZI_AUDIO_MODE MOZZI_OUTPUT_I2S_DAC
#define MOZZI_I2S_FORMAT MOZZI_I2S_FORMAT_LSBJ

#define REFM_NOTE 48
#define REFP_NOTE REFM_NOTE + 24
#define led_pin 6


#elif (HARDWARE_VERSION == PROTO_V2)  // small wood one
#define PRESSURE0_MIN 900
#define PRESSURE0_MAX 3060

#define PRESSURE1_MIN 150
#define PRESSURE1_MAX 700

#define PRESSURE2_MIN 50
#define PRESSURE2_MAX 580

#define PRESSURE3_MIN 0
#define PRESSURE3_MAX 600

#define REFM_NOTE 46
#define REFP_NOTE REFM_NOTE + 19

#define led_pin LED_BUILTIN
#endif


#define FM_RATIO_MOD_FREE

#ifdef FM_RATIO_MOD_FREE
//#define LUT_FM_RATIO_FULL // add a LUT to the modRatio which flattens on every full integer values, can also be LUT_FM_RATIO_HALF
#define LUT_FM_RATIO_HALF
#define LUT_FM_RATIO_TAME 1
#endif


#endif

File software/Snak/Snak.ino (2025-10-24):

/*
Copyright 2024, 2025 Thomas Combriat/TES

This is licensed under the GPL Licence

This is a variant firmware for the polyphonic version
of Boelgene, a polyphonic Ondes Martenot inspired instrument.

This implements formant synthesis, with two bandpass filters
evolving with pressure on the keys, potentially giving voice type
of sounds.

*/

#include "MozziConfigValues.h"  // for named option values
#include "config.h"
#define MOZZI_BUFFER_SIZE 32
#define MOZZI_CONTROL_RATE 1024  // Hz, powers of 2 are most reliable

#include <Button.h>  // from TES_eSax-lib
#include <Mozzi.h>
#include <mozzi_midi.h>
#include <Oscil.h>
//#include <tables/saw2048_int8.h>
//#include <tables/triangle2048_int8.h>
#include <tables/cos512_int8.h>
#include <tables/cos2048_int8.h>
#include <ResonantFilter.h>
#include <FixMathMapper.h>
#include "BiPot.h"
#include <MetaOscil.h>
#include "Oscils.h"
#include <mozzi_rand.h>
#include <WaveFolder.h>

#include <SPI.h>
#include <MCP3XXX.h>
#include "config.h"
#include "param_struct.h"

#if (defined LUT_FM_RATIO_FULL || defined LUT_FM_RATIO_HALF)
#include "modRatioLUT.hpp"
#endif


FixMathMapperFull<UFix<12, 0>, UFix<7, 9>> mapper;
FixMathMapperFull<UFix<12, 0>, UFix<8, 0>, true> pressure0Mapper;
FixMathMapperFull<UFix<10, 0>, UFix<8, 0>, true> pressure1Mapper;
FixMathMapperFull<UFix<10, 0>, UFix<8, 0>, true> pressure2Mapper;
FixMathMapperFull<UFix<10, 0>, UFix<8, 0>, true> pressure3Mapper;

FixMathMapperFull<UFix<12, 0>, UFix<16, 0>, true> bp1Mapper;
FixMathMapperFull<UFix<12, 0>, UFix<16, 0>, true> bp2Mapper;

WaveFolder<int32_t> wf;

// ADC
MCP3XXX_<10, 8, 300000> adc;


// Pin mapping
const uint8_t pot0 = 3, pot1 = 4, pot2 = 5, pot3 = 6, pot4 = 7, pot5 = 28;
const uint8_t pitch_pin = 27, octm_pin = 9, octp_pin = 8, refm_pin = 7, refp_pin = 3;
const uint8_t pressure_pin0 = 26, pressure_pin1 = 0, pressure_pin2 = 1, pressure_pin3 = 2;

// Octaves plus and minus buttons
Button octm(octm_pin, false);
Button octp(octp_pin, false);

// Global synthesis variables
int octave = 0;
UFix<7, 9> midi_base_note;
UFix<12, 0> pitch_pot_min = 433, pitch_pot_max = 3811;

Params params;




unsigned long last_update_time = 0;

/// LED false Osc
uint8_t led_intensity = 0;


// Maybe boost back to 1 once pressure properly calibrated?

BiPotMultBoost cutoff1Pot(12, 8, 1);
BiPotMultBoost cutoff2Pot(12, 8, 1);



#define OSC_NUM_CELLS 512






class Voice {
public:
  Voice(){};
  Voice(Params *_params) {
    params = _params;
  };
  void setParams(Params *_params) {
    params = _params;
  };

  MetaOscil<OSC_NUM_CELLS, MOZZI_AUDIO_RATE, 14> aSub;
  SFix<4, 0> transpose;
  MetaOscil<OSC_NUM_CELLS, MOZZI_AUDIO_RATE, 14> aSaw;
  MetaOscil<OSC_NUM_CELLS, MOZZI_AUDIO_RATE, 21> aSq;
  Oscil<2048, MOZZI_AUDIO_RATE> aAMod;

  uint8_t volume;
  //LowPassFilter16 lpf;
  ResonantFilter<BANDPASS, uint16_t> bpf1a;
  ResonantFilter<BANDPASS, uint16_t> bpf2a;
  ResonantFilter<BANDPASS, uint16_t> bpf1b;
  ResonantFilter<BANDPASS, uint16_t> bpf2b;


  void setBaseNote(UFix<7, 9> base_note) {
    freq = mtof(base_note + transpose);
    aSaw.setFreq(freq);
    aSq.setFreq(freq.sR<0>());
    aSub.setFreq(freq.sR<1>());
    aAMod.setFreq(freq * params->AMfreqRatio);
  }

  void setCutoff1(uint16_t _cutoff1) {
    cutoff1 = _cutoff1;
    bpf1a.setCutoffFreqAndResonance(cutoff1, params->resonance);
    bpf1b.setCutoffFreqAndResonance(cutoff1, params->resonance);
  }

  void setCutoff2(uint16_t _cutoff2) {
    cutoff2 = _cutoff2;
    bpf2a.setCutoffFreqAndResonance(cutoff2, params->resonance);
    bpf2b.setCutoffFreqAndResonance(cutoff2, params->resonance);
  }

  void setResonance(uint16_t _resonance) {
    resonance = _resonance;
  }  // to allow potential taming further down the road


  int32_t next() {
    //int32_t sample = (params->osc_mix * aSaw.next() + (255 - params->osc_mix) * aSq.next()) >> 8;  // 9bits
    int32_t sample = aSaw.next();  // 8bits
    sample += (aSub.next() * params->sub_level) >> 7;
    //sample = (sample * (aAMod.next() + 127)) >> 8;                                                      //10bits
    int32_t bpfed_sample = volume * (bpf1b.next(bpf1a.next(sample)) + bpf2b.next(bpf2a.next(sample)));  //18
    return (bpfed_sample * (aAMod.next() + 127))>>8;
  }

private:

  UFix<16, 16> freq;
  uint16_t cutoff1, cutoff2, resonance;
  Params *params = nullptr;
};


Voice voices[POLYPHONY];

void setup() {

  Serial.begin(115200);
  // Voices initialization

  for (int i = 0; i < POLYPHONY; i++) {
    aSaw154[i].setTable(SAW_MAX_154_AT_16384_512_DATA);
    aSaw182[i].setTable(SAW_MAX_182_AT_16384_512_DATA);
    aSaw221[i].setTable(SAW_MAX_221_AT_16384_512_DATA);
    aSaw282[i].setTable(SAW_MAX_282_AT_16384_512_DATA);
    aSaw356[i].setTable(SAW_MAX_356_AT_16384_512_DATA);
    aSaw431[i].setTable(SAW_MAX_431_AT_16384_512_DATA);
    aSaw546[i].setTable(SAW_MAX_546_AT_16384_512_DATA);
    aSaw630[i].setTable(SAW_MAX_630_AT_16384_512_DATA);
    aSaw744[i].setTable(SAW_MAX_744_AT_16384_512_DATA);
    aSaw910[i].setTable(SAW_MAX_910_AT_16384_512_DATA);
    aSaw1170[i].setTable(SAW_MAX_1170_AT_16384_512_DATA);
    aSaw1638[i].setTable(SAW_MAX_1638_AT_16384_512_DATA);
    aSaw2730[i].setTable(SAW_MAX_2730_AT_16384_512_DATA);
    aSaw8192[i].setTable(SAW_MAX_8192_AT_16384_512_DATA);

    aSq75[i].setTable(SQUARE_MAX_75_AT_16384_512_DATA);
    aSq81[i].setTable(SQUARE_MAX_81_AT_16384_512_DATA);
    aSq88[i].setTable(SQUARE_MAX_88_AT_16384_512_DATA);
    aSq96[i].setTable(SQUARE_MAX_96_AT_16384_512_DATA);
    aSq106[i].setTable(SQUARE_MAX_106_AT_16384_512_DATA);
    aSq118[i].setTable(SQUARE_MAX_118_AT_16384_512_DATA);
    aSq134[i].setTable(SQUARE_MAX_134_AT_16384_512_DATA);
    aSq154[i].setTable(SQUARE_MAX_154_AT_16384_512_DATA);
    aSq182[i].setTable(SQUARE_MAX_182_AT_16384_512_DATA);
    aSq221[i].setTable(SQUARE_MAX_221_AT_16384_512_DATA);
    aSq282[i].setTable(SQUARE_MAX_282_AT_16384_512_DATA);
    aSq356[i].setTable(SQUARE_MAX_356_AT_16384_512_DATA);
    aSq431[i].setTable(SQUARE_MAX_431_AT_16384_512_DATA);
    aSq546[i].setTable(SQUARE_MAX_546_AT_16384_512_DATA);
    aSq630[i].setTable(SQUARE_MAX_630_AT_16384_512_DATA);
    aSq744[i].setTable(SQUARE_MAX_744_AT_16384_512_DATA);
    aSq910[i].setTable(SQUARE_MAX_910_AT_16384_512_DATA);
    aSq1170[i].setTable(SQUARE_MAX_1170_AT_16384_512_DATA);
    aSq1638[i].setTable(SQUARE_MAX_1638_AT_16384_512_DATA);
    aSq2730[i].setTable(SQUARE_MAX_2730_AT_16384_512_DATA);
    aSq8192[i].setTable(SQUARE_MAX_8192_AT_16384_512_DATA);
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

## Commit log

2024-09-25 Added kicad components
2024-09-25 Added initial kicad project
    [Boelgene_v1.kicad_sch]
2024-09-25 Updated sch
    [Boelgene_v1.kicad_sch]
2024-09-28 Started pcb
    [Boelgene_v1.kicad_pcb]
2024-09-28 Routing of pcb
    [Boelgene_v1.kicad_pcb, Boelgene_v1.kicad_sch]
2024-10-29 Updated PCB
    [Boelgene_v1.kicad_pcb, Boelgene_v1.kicad_sch]
2025-01-21 Actual version 1.1
    [Boelgene_v1d1.kicad_pcb, Boelgene_v1d1.kicad_sch]
2025-01-21 Removed unneeded files
    [Boelgene_v1d1.kicad_pcb]
2025-01-21 Update after zone filling
    [Boelgene_v1d1.kicad_pcb]
2025-01-21 Added gerber export
    [Boelgene_v1d1-B_Cu.gbr, Boelgene_v1d1-B_Mask.gbr, Boelgene_v1d1-B_Paste.gbr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]
2025-01-21 Added automatically generated Bom
    [Boelgene_v1d1.csv]
2025-01-22 Added BOM
    [BOM.xls]
2025-01-22 Added correct ribbon input reference
    [Boelgene_v1d1.kicad_pcb, Boelgene_v1d1.kicad_sch]
2025-01-22 Updated gerber
    [Boelgene_v1d1-B_Cu.gbr, Boelgene_v1d1-B_Mask.gbr, Boelgene_v1d1-B_Paste.gbr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]
2025-02-01 Updated bom
    [BOM.xls]
2025-02-04 Updated the mappers to new version of FixMath
    [FMisNOTdead.ino, boelgene_1.ino, boelgene_poly.ino]
2025-02-06 Added calibration script
2025-02-06 Calibrated pressure for full range
2025-02-26 Added FMRatio LUT to ease landing on int/half int ratio
2025-03-30 Updated PCB with connectors
    [Boelgene_v1d1.kicad_pcb, Boelgene_v1d1.kicad_sch]
2025-04-05 Added TH Pico model
2025-04-08 Added brak logo
    [Boelgene_v1d1-B_Cu.gbr, Boelgene_v1d1-B_Mask.gbr, Boelgene_v1d1-B_Paste.gbr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]
2025-04-08 Added Mozzi ref
    [Boelgene_v1d1-B_Cu.gbr, Boelgene_v1d1-B_Mask.gbr, Boelgene_v1d1-B_Paste.gbr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]
2025-09-17 First tries on Formant synthesis
    Added noise to formant synth
    [Snak.ino, config.h]
2025-10-06 Added 3D CAD for proto v2
    [Bottom_common_1.STL, Top_common_1.STL, Top_oversize_1.STL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]
2025-10-07 Added Wiring guide
2025-10-08 Started fingerboard drawing
    [assembly.FCStd, full_fret.FCStd, half_base.FCStd]
2025-10-08 Better axis
    [axis_small_idler_bump-Corps.stl, axis_small_idler_bump.FCStd]
2025-10-08 Added OnOff holder
    [OnOff_holder-Corps.stl, OnOff_holder.FCStd]
2025-10-08 Changed to fretboard with moveable holes
    [half_base.FCStd]
2025-10-09 More options for fingerboard
    [full_fret-Corps.stl, full_fret.FCStd, half_base-Corps.stl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]
2025-10-09 Added symbols
    [pot_top4_part1.STL]
2025-10-17 Proto v2 moved to PWM
